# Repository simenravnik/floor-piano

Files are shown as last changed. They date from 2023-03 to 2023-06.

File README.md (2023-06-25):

# Floor piano

## Prerequisites

1. 5x [ESP32](https://www.espressif.com/en/products/socs/esp32)
2. 4x [MPR121](https://components101.com/modules/mpr121-capacitive-touch-sensor-module)
3. [VS1003 (or VS1053)](https://www.vlsi.fi/fileadmin/datasheets/vs1003.pdf)
4. [KY-040 (Rotary Encoder)](http://handsontec.com/dataspecs/module/Rotary%20Encoder.pdf)

## Schematics

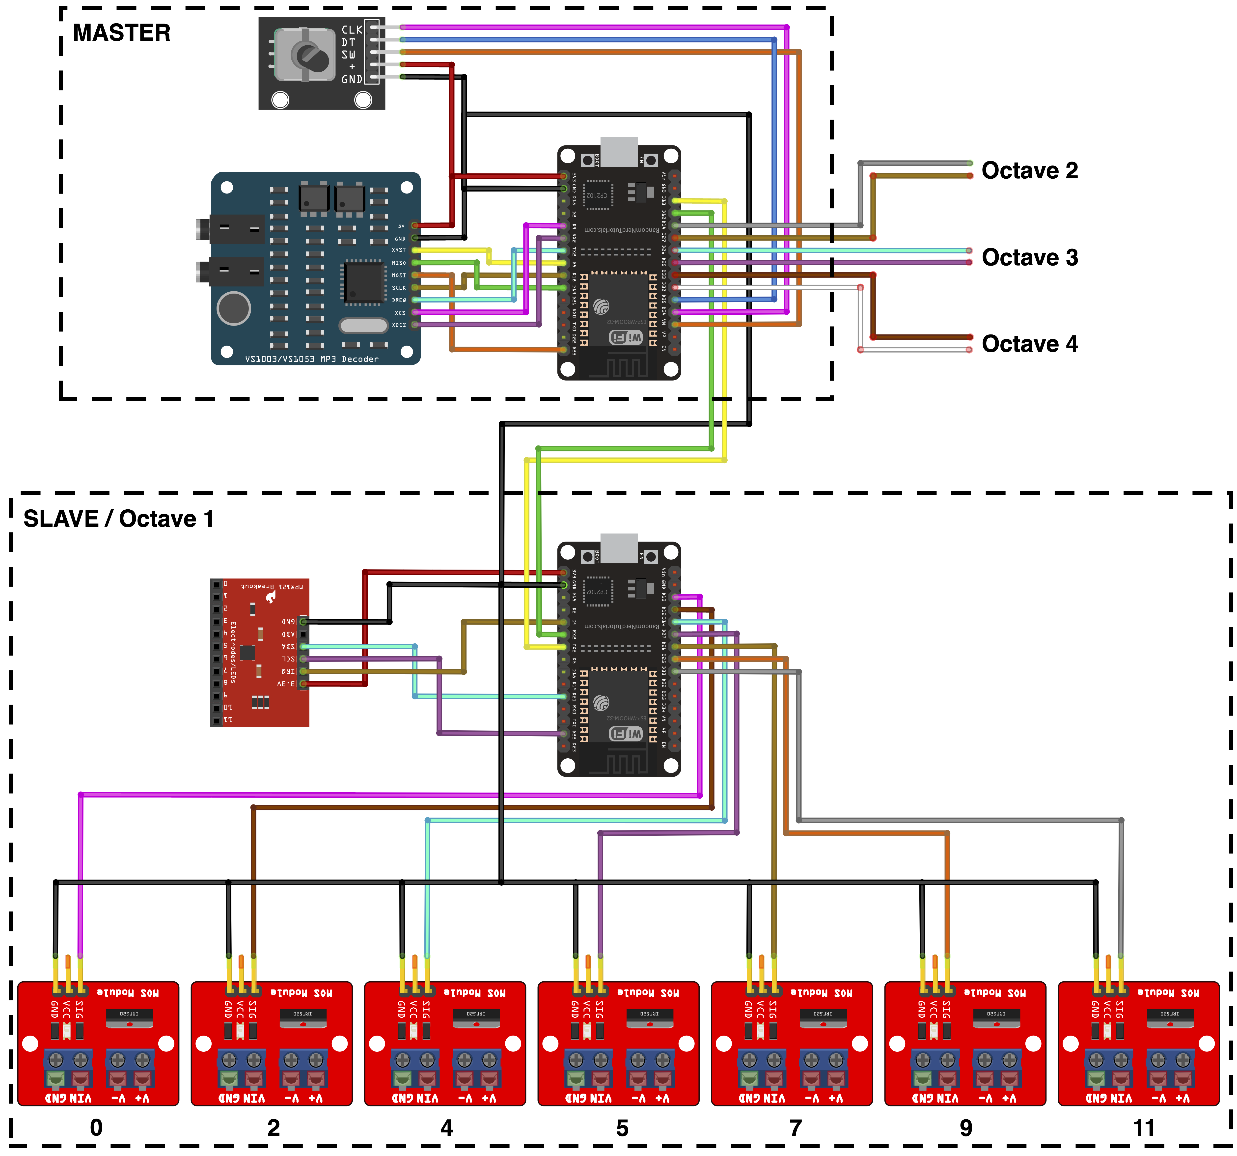
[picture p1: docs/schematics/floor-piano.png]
Piano Schematics

# Installation instructions
# Slave

Upload [`slave/slave.ino`](slave/slave.ino) to 4 ESP32 boards and connect it to master according to schematics. The slaves are mutually **independent**, allowing each of them to work independently also when others are not connected to the master. For more detailed wiring look at the source `slave.ino` file.

# Master

Upload [`master/master.ino`](master/master.ino) to 1 ESP32 board and connect the peripheral devices according to schematics. For more detailed wiring look at the source `master.ino` file.

## Wiring

### 1. VS1003

The VS1003 module is used for audio playback. Connect the VS1003 pins to the ESP32 as follows:

| VS1003  |  ESP32  | ESP32 (GPIO) |
|:---:|:---:|:---:|
| SCLK  | D18 | 18 |
| MISO  | D19 | 19 |
| MOSI  | D23 | 23 |
| XRST  | D5 | 5 |
| CS | D4 | 4 |
| XDCS  | RX2 | 16 |
| DREQ  | TX2 | 17 |
| 5V | 3.3V  | 3.3V |
| GND | GND | GND |

### 2. Octaves (UART)

The program supports up to 4 Octave devices connected through UART communication. Connect the RX pins from the slave controllers to the TX pins on the master controller, and the TX pins from the slave controllers to the master RX pins on the master controller. The following table describes the wiring for each Octave device:

Octave 1:
| UART 1  |  ESP32  | ESP32 (GPIO) |
|:---:|:---:|:---:|
| RX | D13 | 13 |
| TX | D12 | 12 |

Octave 2:
| UART 2  |  ESP32  | ESP32 (GPIO) |
|:---:|:---:|:---:|
| RX | D14 | 14 |
| TX | D27 | 27 |

Octave 3:
| UART 3  |  ESP32  | ESP32 (GPIO) |
|:---:|:---:|:---:|
| RX | D26 | 26 |
| TX | D25 | 25 |

Octave 4:
| UART 4  |  ESP32  | ESP32 (GPIO) |
|:---:|:---:|:---:|
| RX | D33 | 33 |
| TX | D32 | 32 |

### 3. Rotary Encoder

A rotary encoder is used to select the channel (instrument). Connect the rotary encoder pins to the ESP32 as follows:

| KY-040  |  ESP32  | ESP32 (GPIO) |
|:---:|:---:|:---:|
| CLK | D34 | 34 |
| DT | D35 | 35 |
| SW | VN | 39 |

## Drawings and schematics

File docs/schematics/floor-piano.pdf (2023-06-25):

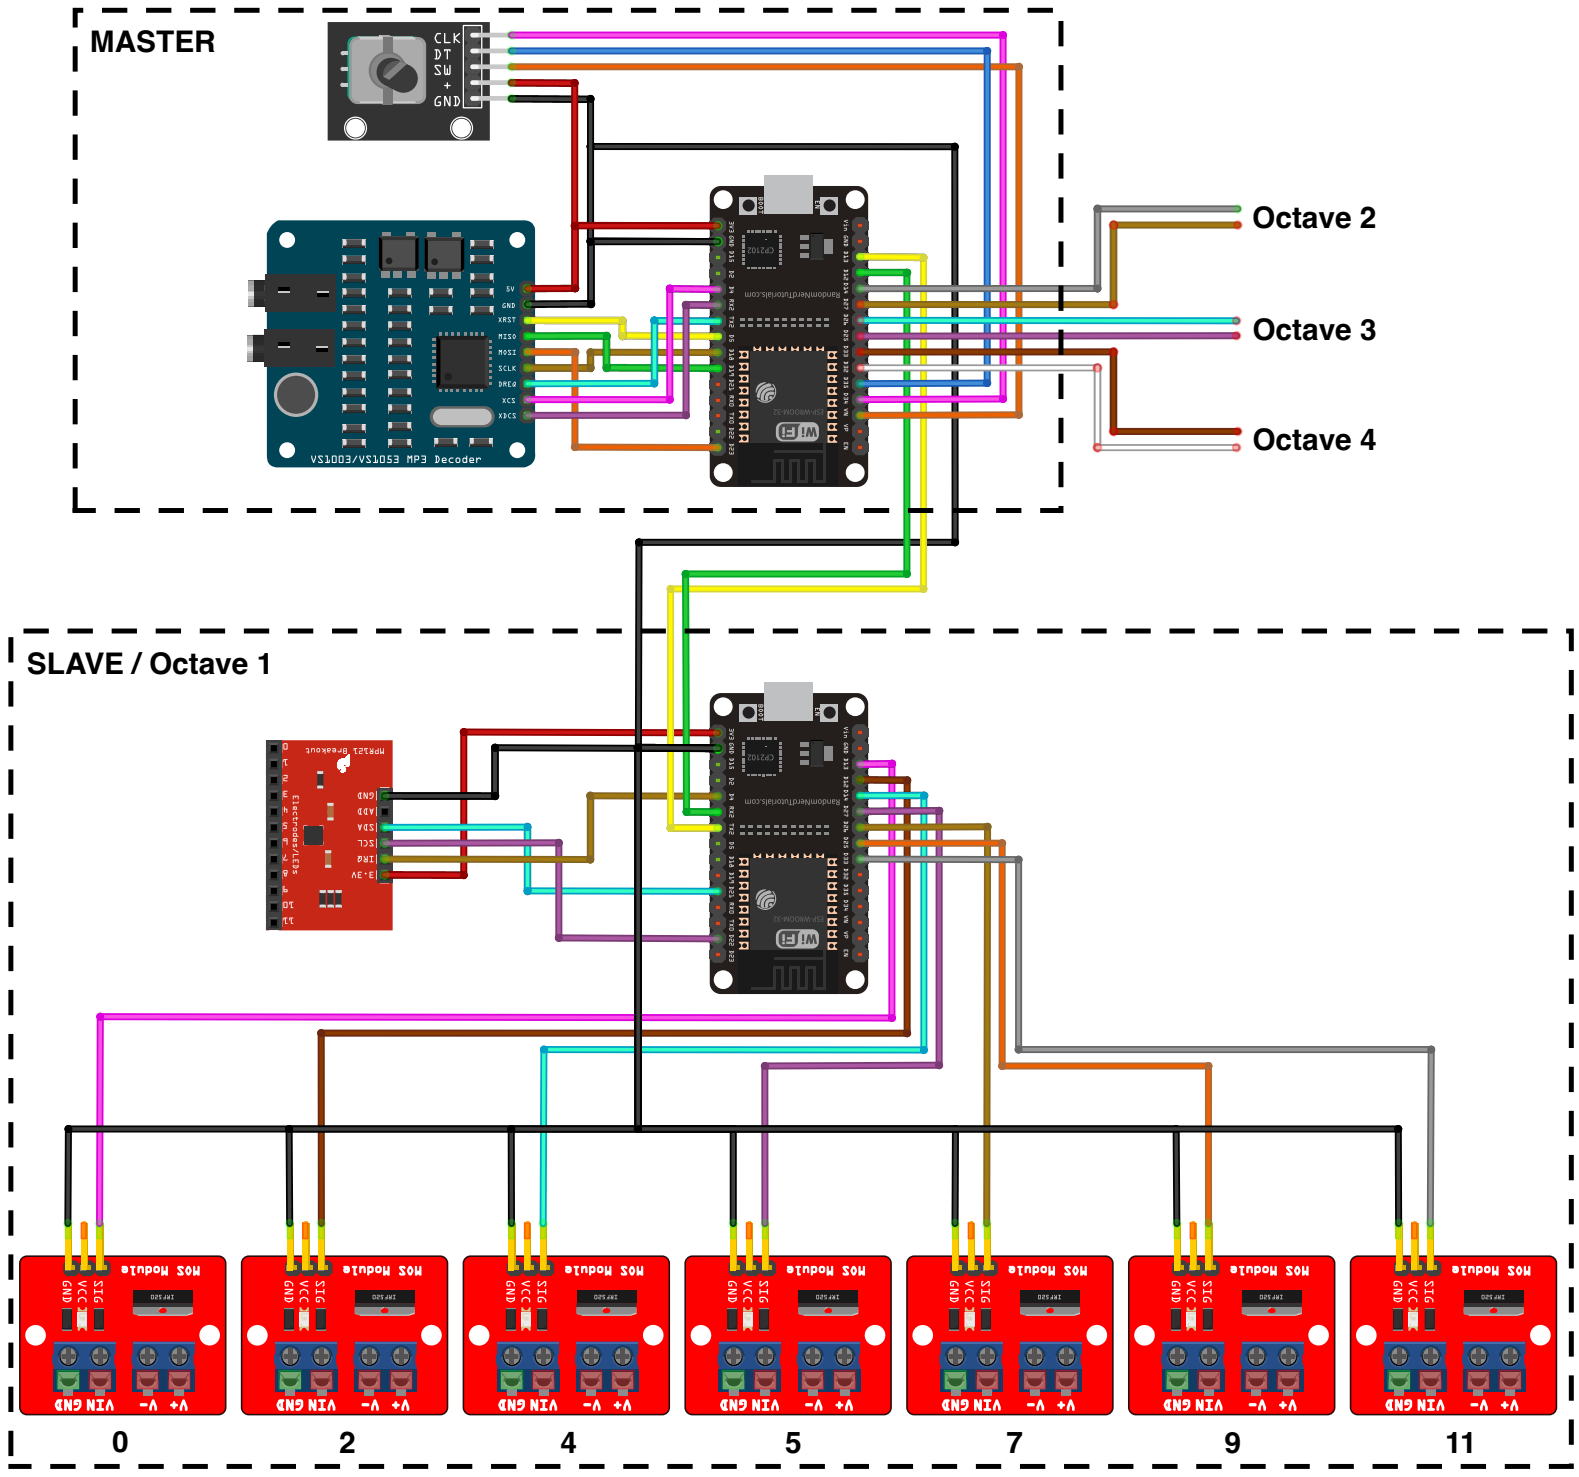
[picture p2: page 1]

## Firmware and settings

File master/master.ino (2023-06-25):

#include "src/VS/VS10XX.h"
#include <Wire.h>
#include "src/espsoftwareserial/src/SoftwareSerial.h"

/**
    Wiring (master):

    1. VS1003
    ------------------------------------
    | VS1003  |  ESP32  | ESP32 (GPIO) |
    ------------------------------------
    |   SCLK  |   D18   |     18       |
    |   MISO  |   D19   |     19       |
    |   MOSI  |   D23   |     23       |
    |   XRST  |   D5    |     5        |
    |   CS    |   D4    |     4        |
    |   XDCS  |   RX2   |     16       |
    |   DREQ  |   TX2   |     17       |
    |   5V    |   3.3V  |     3.3V     |
    |   GND   |   GND   |     GND      |
    ------------------------------------

    2. Octaves (UART)

    Connect RX pins from slave controllers to TX pins on master controller,
    and TX pins from slave controllers to master TX pins on master controller.

    Octave 1:
    ------------------------------------
    | UART 1  |  ESP32  | ESP32 (GPIO) |
    ------------------------------------
    |   RX    |   D13   |     13       |
    |   TX    |   D12   |     12       |
    ------------------------------------

    Octave 2:
    ------------------------------------
    | UART 2  |  ESP32  | ESP32 (GPIO) |
    ------------------------------------
    |   RX    |   D14   |     14       |
    |   TX    |   D27   |     27       |
    ------------------------------------

    Octave 3:
    ------------------------------------
    | UART 3  |  ESP32  | ESP32 (GPIO) |
    ------------------------------------
    |   RX    |   D26   |     26       |
    |   TX    |   D25   |     25       |
    ------------------------------------

    Octave 4:
    ------------------------------------
    | UART 4  |  ESP32  | ESP32 (GPIO) |
    ------------------------------------
    |   RX    |   D33   |     33       |
    |   TX    |   D32   |     32       |
    ------------------------------------

    1. Rotary Encoder
    ------------------------------------
    | KY-040  |  ESP32  | ESP32 (GPIO) |
    ------------------------------------
    |   CLK   |   D34   |     34       |
    |   DT    |   D35   |     35       |
    |   SW    |   VN    |     39       |
    ------------------------------------
**/

// VS1003 pin definitions
#define VS_XCS 4   // Control Chip Select Pin (for accessing SPI Control/Status registers)
#define VS_XDCS 16 // Data Chip Select / BSYNC Pin
#define VS_DREQ 17 // Data Request Pin: Player asks for more data
#define VS_RESET 5 // Reset is active low

// VS10xx SPI pin connections
// Provided here for info only - not used in the sketch as the SPI library handles this
#define VS_MOSI 23
#define VS_MISO 19
#define VS_SCK 18
#define VS_SS 5

VS10XX vs10xx(VS_XCS, VS_XDCS, VS_DREQ, VS_RESET, VS_SS);

// UART communication
#define numOctaves 4

uint8_t RxTx[numOctaves][2] = {
    {13, 12}, // RX, TX
    {14, 27},
    {26, 25},
    {33, 32}};

SoftwareSerial *connections[numOctaves] = {
    new SoftwareSerial(),
    new SoftwareSerial(),
    new SoftwareSerial(),
    new SoftwareSerial()};

uint8_t message[numOctaves][1];

// Rotary Encoder
#define CLK 34
#define DT 35
#define SW 39

bool rotaryEncoderActive; // True or False
unsigned long lastButtonPress = 0;
int8_t channel;
int8_t prevChannel;

int currentStateCLK;
int lastStateCLK;

void setup()
{

  Serial.begin(115200);
  Serial.println("System started");

  // Initialize all 4 UART connections
  for (int i = 0; i < numOctaves; i++)
  {
    connections[i]->begin(38400, SWSERIAL_8N1, RxTx[i][0], RxTx[i][1], false);
    if (!connections[i])
    { // If the object did not initialize, then its configuration is invalid
      Serial.println("Invalid SoftwareSerial pin configuration, check config");
      while (1)
      { // Don't continue with invalid configuration
        delay(1000);
      }
    }
    message[i][0] = -1;
  }

  Serial.println("Initialising VS10xx");
  // put your setup code here, to run once:
  vs10xx.initialiseVS10xx();
  delay(1000);

  // Set encoder pins as inputs
  pinMode(CLK, INPUT);
  pinMode(DT, INPUT);
  pinMode(SW, INPUT);

  rotaryEncoderActive = false;
  channel = 0;
  prevChannel = 0;

  lastStateCLK = digitalRead(CLK);
}

#define OCTAVE_1 48
#define OCTAVE_2 60

void loop()
{

  // ROTARY ENCODER
  checkButtonPressed();

  if (rotaryEncoderActive)
  {
    updateEncoder();
  }

  // VS10xx
  for (uint8_t i = 0; i < numOctaves; i++)
  {
    if (connections[i]->available())
    {
      connections[i]->readBytes(message[i], sizeof(message[i]));

      if (message[i][0] >= 0 && message[i][0] < 12)
      {
        // Serial.println(message[i][0]);
        uint8_t note = message[i][0] + (36 + (12 * i));
        vs10xx.noteOn(channel, note, 127);
      }
      else if (message[i][0] >= 12)
      {
        // Serial.println(message[i][0]);
        uint8_t note = message[i][0] - 12 + (36 + (12 * i));
        vs10xx.noteOff(channel, note, 127);
      }

      message[i][0] = -1;
    }
  }
}

void checkButtonPressed()
{
  // Update rotary encoder state when the button was pressed
  if (digitalRead(SW) == LOW)
  {
    // If the interval between last and current press is larger than 50ms
    if (millis() - lastButtonPress > 50)
    {
      rotaryEncoderActive = !rotaryEncoderActive;
    }
    lastButtonPress = millis();
  }
}

void updateEncoder()
{
  // Read the current state of CLK
  currentStateCLK = digitalRead(CLK);

  // If last and current state of CLK are different, then pulse occurred
  // React to only 1 state change to avoid double count
  if (currentStateCLK != lastStateCLK && currentStateCLK == 1)
  {

    // If the DT state is different than the CLK state then
    // the encoder is rotating CCW so decrement
    if (digitalRead(DT) != currentStateCLK)
    {
      channel = (channel - 1) % 16;
      if (channel < 0)
      {
        channel = 0;
      }
    }
    else
    {
      // Encoder is rotating CW so increment
      channel = (channel + 1) % 16;
    }

    // Turn off currently playing notes
    for (int j = 0; j < 12; j++)
    {
      uint8_t noteOctave1 = j + 36;
      uint8_t noteOctave2 = j + 36 + (12 * 1);
      uint8_t noteOctave3 = j + 36 + (12 * 2);
      uint8_t noteOctave4 = j + 36 + (12 * 2);
      vs10xx.noteOff(prevChannel, noteOctave1, 127);
      vs10xx.noteOff(prevChannel, noteOctave2, 127);
      vs10xx.noteOff(prevChannel, noteOctave3, 127);
      vs10xx.noteOff(prevChannel, noteOctave4, 127);
    }
    prevChannel = channel;
  }

  // Remember last CLK state
  lastStateCLK = currentStateCLK;
}

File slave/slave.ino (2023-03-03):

#include <Arduino.h>
#include "src/MPR/MPR121.h"
#include "src/espsoftwareserial/src/SoftwareSerial.h"

/**
    Wiring (slave):

    1. MPR121

    ------------------------------------
    | MPR121  |  ESP32  | ESP32 (GPIO) |
    ------------------------------------
    |   IRQ   |   D4    |     4        |
    |   SCL   |   D22   |     22       |
    |   SDA   |   D21   |     21       |
    |   ADD   |   -     |     -        |
    |   3.3V  |   3.3V  |     3.3V     |
    |   GND   |   GND   |     GND      |
    ------------------------------------

    2. UART

    ------------------------------------
    |  UART   |  ESP32  | ESP32 (GPIO) |
    ------------------------------------
    |   RX    |   RX2   |     16       |
    |   TX    |   TX2   |     17       |
    ------------------------------------

    3. LEDs

    Electrodes from MPR121 that are connected to
    GPIO pins which serves as outputs for LEDs.

    --------------------------------------
    | Electrode |  ESP32  | ESP32 (GPIO) |
    --------------------------------------
    |     0     |   D13   |     13       |
    |     1     |    -    |      -       |
    |     2     |   D12   |     12       |
    |     3     |    -    |      -       |
    |     4     |   D14   |     14       |
    |     5     |   D27   |     27       |
    |     6     |    -    |      -       |
    |     7     |   D26   |     26       |
    |     8     |    -    |      -       |
    |     9     |   D25   |     25       |
    |     10    |    -    |      -       |
    |     11    |   D33   |     33       |
    --------------------------------------

**/

// MPR121
#define INTERUPT_PIN 4
#define numElectrodes 12

MPR121_type MPR121_1;

#define MYPORT_TX 17
#define MYPORT_RX 16

SoftwareSerial mySerial;

uint8_t LEDS[numElectrodes] = {13, 0, 12, 0, 14, 27, 0, 26, 0, 25, 0, 33};

void setup()
{
  Serial.begin(115200);
  Serial.println("System started");

  mySerial.begin(38400, SWSERIAL_8N1, MYPORT_RX, MYPORT_TX, false);
  if (!mySerial)
  { // If the object did not initialize, then its configuration is invalid
    Serial.println("Invalid SoftwareSerial pin configuration, check config");
    while (1)
    { // Don't continue with invalid configuration
      delay(1000);
    }
  }

  if (!MPR121.begin(0x5A))
  {

    Serial.println("error setting up MPR121");
    switch (MPR121.getError())
    {
    case NO_ERROR:
      Serial.println("no error");
      break;
    case ADDRESS_UNKNOWN:
      Serial.println("incorrect address");
      break;
    case READBACK_FAIL:
      Serial.println("readback failure");
      break;
    case OVERCURRENT_FLAG:
      Serial.println("overcurrent on REXT pin");
      break;
    case OUT_OF_RANGE:
      Serial.println("electrode out of range");
      break;
    case NOT_INITED:
      Serial.println("not initialised");
      break;
    default:
      Serial.println("unknown error");
      break;
    }
  }

  MPR121.setInterruptPin(INTERUPT_PIN);
  MPR121.setTouchThreshold(40);
  MPR121.setReleaseThreshold(20);
  MPR121.updateTouchData();

  for (uint8_t i = 0; i < numElectrodes; i++)
  {
    if (LEDS[i] != 0)
    {
      pinMode(LEDS[i], OUTPUT); // set ESP32 pin to output mode
    }
  }
}

void loop()
{
  // Read MPR121 and play notes accordingly
  if (MPR121.touchStatusChanged())
  {
    MPR121.updateTouchData();
    for (uint8_t i = 0; i < numElectrodes; i++)
    {
      if (MPR121.isNewTouch(i))
      {
        // Serial.println(i);
        mySerial.write(i);
        ledOn(i);
      }
      else if (MPR121.isNewRelease(i))
      {
        // Serial.println(i + 12);
        mySerial.write(i + 12);
        ledOff(i);
      }
    }
  }
}

void ledOn(uint8_t pin)
{
  if (LEDS[pin] != 0)
  {
    digitalWrite(LEDS[pin], HIGH);
  }
}

void ledOff(uint8_t pin)
{
  if (LEDS[pin] != 0)
  {
    digitalWrite(LEDS[pin], LOW);
  }
}

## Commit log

2022-12-01 Implement UART communication between microcontrollers
2022-12-07 Add initial Pico python implementation for reading MPR121 sensor
2022-12-08 Add UART communication from Pico to master controller
2022-12-08 Update UART communication in master.ino
2022-12-08 Add initial schemantics for Pico and MPR121
    [one-octave.fzz]
2022-12-11 Add moving average filter to smooth MPR121 signal
2022-12-25 Implement arduino VS10XX library for audio interface
2023-03-02 Remove current VS10XX lib implementation
2023-03-02 Update pitch based on the UART connection
2023-03-02 Implement LED pins according to MPR121 electrodes
2023-03-03 Add new schematics for first octave
    [floor-piano.fzz]
2023-03-03 Remove PICO implementation and old schematics
    [one-octave.fzz]
2023-03-03 Add wiring information at the beginning of master and slave arduino scripts
2023-03-04 Update wiring schema
    [floor-piano.fzz]
2023-03-07 Add rotary encoder for instrument switching to master.ino
2023-03-08 Implement turning off currently playing notes on channel switch
2023-03-08 Fix wiring information comment in master.ino
    [master.ino]
2023-06-25 Update rotary encoder wiring instruction in master.ino
2023-06-25 Update schematics and README.md
    [floor-piano.fzz]
